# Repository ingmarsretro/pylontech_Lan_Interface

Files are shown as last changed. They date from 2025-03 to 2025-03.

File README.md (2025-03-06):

# Universal LAN Board with WT32-ETH01 Module for Pylontech and more

This project introduces a universal board that can be used for various purposes. The heart of the board is a WT32-ETH01 module with an ESP32 and a LAN interface. Depending on the configuration and software, the board can fulfill different functions.

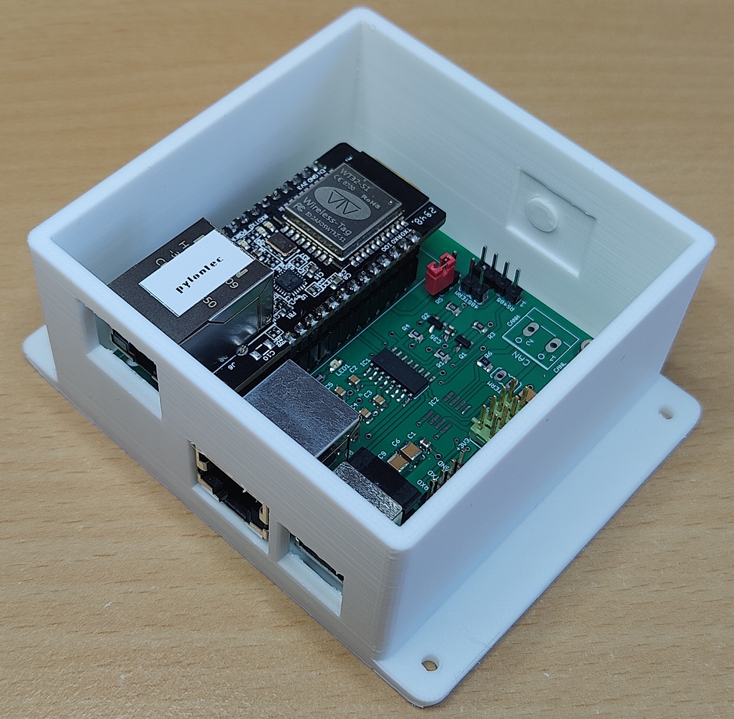
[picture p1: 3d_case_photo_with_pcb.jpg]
3D Case Photo with PCB


## Features

### Communication with Pylontech Solar Batteries

The board can communicate with Pylontech solar batteries (US2000, US3000c, ...) via the serial console interface. For this purpose, the software from the following repositories has been adapted from ESP8266 to ESP32:
- [Pylontech-Battery-Monitoring by irekzielinski](https://github.com/irekzielinski/Pylontech-Battery-Monitoring)
- [PylontechMonitoring by hidaba](https://github.com/hidaba/PylontechMonitoring)

Thus, the Pylontech batteries can communicate via LAN over MQTT with, for example, Homeassistant.

### Communication with Microinverters (e.g., Hoymiles)

The board can communicate with microinverters such as Hoymiles via OpenDTU software and the NRF24L01+ module:
- [OpenDTU by tbnobody](https://github.com/tbnobody/OpenDTU)

A configuration file for OpenDTU with WS32ETH 01 is included and can be adjusted if necessary. Further information for current software can be found on the OpenDTU GitHub.

### Communication via CAN or RS485

The board can communicate with various devices via CAN or RS485. Projects for this will be developed or published as needed.

## Installation

1. **Prepare Hardware:**
   - Assemble the board according to the desired functionality (e.g., NRF24L01+ module for OpenDTU or MAX3232 along with console connector for Pylontech).
   - Connect the WT32-ETH01 module to your network and the assembled function to your device (e.g., serial console interface for Pylontech batteries).

2. **Install Software:**
   - Download the appropriate software from the repositories mentioned above.
   - Adjust the configuration files to your needs.
   - Flash the software onto the WT32-ETH01 module. (In the Pylontech software script, IP addresses need to be adjusted. Use Arduino IDE for compiling.)
     To flash the software, a USB_RS232 interface is required. The "Prog" jumper must be set. The programmer is connected to the "TO-FTDI" pins.

3. **Configuration:**
   - When using with Pylontech, enter the address specified in the code in your web browser. If the connection is OK, the data of the Pylontech batteries will be displayed in the browser.
     If an MQTT server is present and correctly specified in the code, MQTT messages will be sent.
   - When using with OpenDTU, configure the network via the OpenDTU access point after flashing the firmware and load the wt32mapping.json file.
   - Ensure all connections are correct and start the system.

## Usage

Depending on configuration and software, you can use the board for various purposes:
- **Pylontech Batteries:** Monitor and control your Pylontech solar batteries via MQTT and integrate them into Homeassistant.
- **Microinverter:** Communicate with microinverters like Hoymiles via OpenDTU and monitor your solar system.
- **CAN/RS485:** Develop your own projects for communication via CAN or RS485 with various devices.

## License
free

# Universalboard mit WT32-ETH01 Modul

Dieses Projekt stellt ein Universalboard vor, das für verschiedene Zwecke verwendet werden kann. Das Herzstück des Boards ist ein WT32-ETH01 Modul mit einem ESP32 und einem LAN Interface. Je nach Bestückung und Software kann das Board verschiedene Funktionen erfüllen.

3D Case Photo with PCB

## Funktionen

### Kommunikation mit Pylontech Solarbatterien

Das Board kann mit den Solarbatterien von Pylontech (US2000, US3000c, ...) über die serielle Console-Schnittstelle kommunizieren. Dafür wurde die Software von folgenden Repositories vom ESP8266 auf den ESP32 angepasst:
- [Pylontech-Battery-Monitoring von irekzielinski](https://github.com/irekzielinski/Pylontech-Battery-Monitoring)
- [PylontechMonitoring von hidaba](https://github.com/hidaba/PylontechMonitoring)

So können die Pylontech Batterien per LAN über MQTT mit z.B. Homeassistant kommunizieren.

### Kommunikation mit Microinvertern (z.B. Hoymiles)

Das Board kann mit Microinvertern wie z.B. Hoymiles per OpenDTU Software und dem NRF24L01+ Modul kommunizieren:
- [OpenDTU von tbnobody](https://github.com/tbnobody/OpenDTU)

Ein Konfigurationsfile für openDTU mit WS32ETH 01 ist beigelegt und kann ggf angepasst werden. Weitere für aktuelle Software auf openDTU git

### Kommunikation über CAN oder RS485

Das Board kann über CAN bzw. RS485 mit beliebigen Geräten kommunizieren. Projekte dazu werden entwickelt bzw. veröffentlicht, sobald sie benötigt werden.

## Installation

1. **Hardware vorbereiten:**
   - Bestücke das Board je nach gewünschter Funktionalität (z.B. NRF24L01+ Modul für OpenDTU oder MAX3232 samt Console Conector für Pylontech)
   - Verbinde das WT32-ETH01 Modul mit deinem Netzwerk und die bestückte Funtkion mit deinem Gerät (z.B. serielle Console-Schnittstelle für Pylontech Batterien).

2. **Software installieren:**
   - Lade die entsprechende Software aus den oben genannten Repositories herunter. 
   - Passe die Konfigurationsdateien an deine Bedürfnisse an. 
   - Flashe die Software auf das WT32-ETH01 Modul. (im Pylontech Softwarescript müssen die IP Adressen angepasst werden. zum kompilieren z.b. Adruino IDE verwenden)
     Zum flashen der Software ist ein USB_RS232 Interface notwendig. Der Jumper "Prog" muss gesetzt sein. Der Programmer wird an den Pins "TO-FTDI" angeschlossen

3. **Konfiguration:**
   - bei Verwendung mit Pylontech im Webbrowser die im code eingegeben Adresse eingeben. Ist die Verbindung OK werden die Daten der Pylontech Batterien im Browser angezeigt.
     Ist der MQTT Server vorhanden und im code richtig angegeben dann werden die mqtt messages gesendet
   - bei Verwednung mit openDTU ist nach dem Flashen der Firmware über den openDTU accesspoint das Netzwerk zu konfigurieren und das wt32mapping.json file zu laden.
   - Stelle sicher, dass alle Verbindungen korrekt sind und starte das System.

## Nutzung

Je nach Bestückung und Software kannst du das Board für verschiedene Zwecke nutzen:
- **Pylontech Batterien:** Überwache und steuere deine Pylontech Solarbatterien über MQTT und integriere sie in Homeassistant.
- **Microinverter:** Kommuniziere mit Microinvertern wie Hoymiles über OpenDTU und überwache deine Solaranlage.
- **CAN/RS485:** Entwickle eigene Projekte zur Kommunikation über CAN oder RS485 mit verschiedenen Geräten.

## Lizenz
free

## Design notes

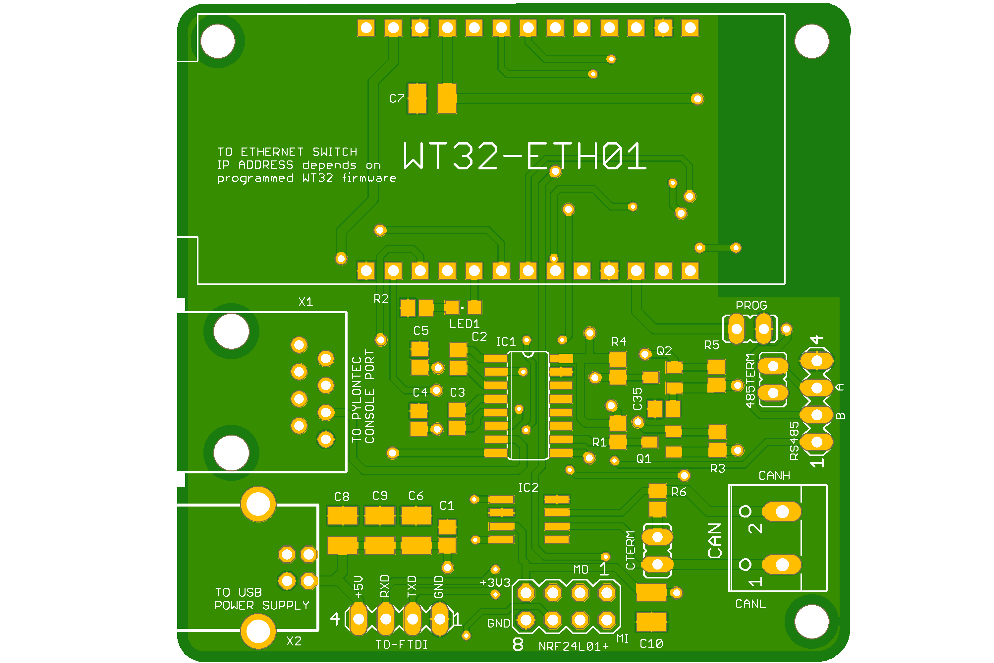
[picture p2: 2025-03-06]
PCB_design/pylontec_LAN_interface.png

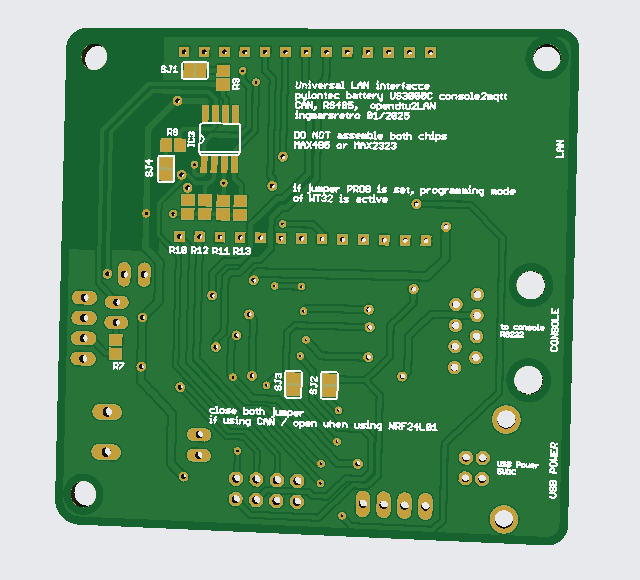
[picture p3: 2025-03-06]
PCB_design/pcb_bott.PNG

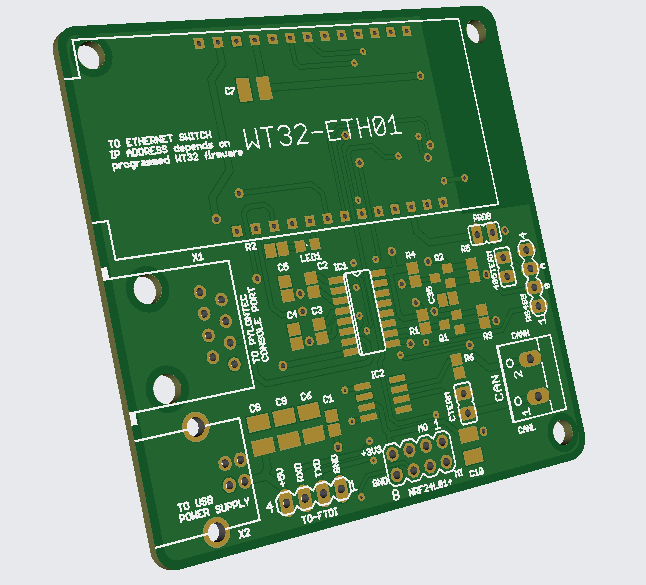
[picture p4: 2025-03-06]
PCB_design/pcb_top.PNG

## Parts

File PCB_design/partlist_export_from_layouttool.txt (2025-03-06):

Partlist

Exported from pylontec_LAN_interface.sch at 06.03.2025 11:38

Assembly variant: 

Part      Value          Device              Package          Library                 Sheet

485TERM                  JP1E                JP1              jumper                  1
C1        100nF          C-EUC0805           C0805            resistor                1
C2        47n            C-EUC0805           C0805            resistor                1
C3        330n           C-EUC0805           C0805            resistor                1
C4        330n           C-EUC0805           C0805            resistor                1
C5        330n           C-EUC0805           C0805            resistor                1
C6        1uF            C-EUC1210           C1210            rcl                     1
C7        1uF            C-EUC1210           C1210            rcl                     1
C8                       C-EUC1210           C1210            rcl                     1
C9                       C-EUC1210           C1210            rcl                     1
C10       1uF            C-EUC1210           C1210            rcl                     1
C35       100nF          C-EUC0805           C0805            resistor                1
CAN                      W237-102            W237-102         con-wago-500            1
CTERM                    JP1E                JP1              jumper                  1
IC1       MAX3232CSE     MAX3232CSE          SO16             maxim                   1
IC2       SN65HVD230     TJA1040             SO8              nxp                     1
IC3       MAX485         MAX481CSA           SO08             maxim                   1
LED1                     LED_LEDCHIPLED_0805 LED_CHIPLED_0805 arduino_Uno_ref         1
NRF24L01+                MA04-2              MA04-2           con-lstb                1
PROG                     JP1E                JP1              jumper                  1
Q1        BSS123         BSS123              SOT23            transistor-small-signal 1
Q2        BSS123         BSS123              SOT23            transistor-small-signal 1
R1        10k            R-EU_R0805          R0805            resistor                1
R2        180R           R-EU_R0805          R0805            resistor                1
R3        10k            R-EU_R0805          R0805            resistor                1
R4        10k            R-EU_R0805          R0805            resistor                1
R5        10k            R-EU_R0805          R0805            resistor                1
R6        120R           R-EU_R0805          R0805            resistor                1
R7        120R           R-EU_R0805          R0805            resistor                1
R8        1k             R-EU_R0805          R0805            resistor                1
R9        1k             R-EU_R0805          R0805            resistor                1
R10       10k            R-EU_R0805          R0805            resistor                1
R11       10k            R-EU_R0805          R0805            resistor                1
R12       10k            R-EU_R0805          R0805            resistor                1
R13       10k            R-EU_R0805          R0805            resistor                1
RS485                    MA04-1              MA04-1           con-lstb                1
SJ1                      SJ                  SJ               jumper                  1
SJ2                      SJ                  SJ               jumper                  1
SJ3                      SJ                  SJ               jumper                  1
SJ4                      SJ                  SJ               jumper                  1
TO-FTDI                  MA04-1              MA04-1           con-lstb                1
U$2       WT32-ETH01     WT32-ETH01          WT32-ETH01       WT32-ETH01              1
X1        RJ45-8L-B      RJ45-8L-B           RJ45-NO-SHIELD   con-tycoelectronics     1
X2                       SMARTPRJ_PN61729    SMARTPRJ_PN61729 arduino_Uno_ref         1

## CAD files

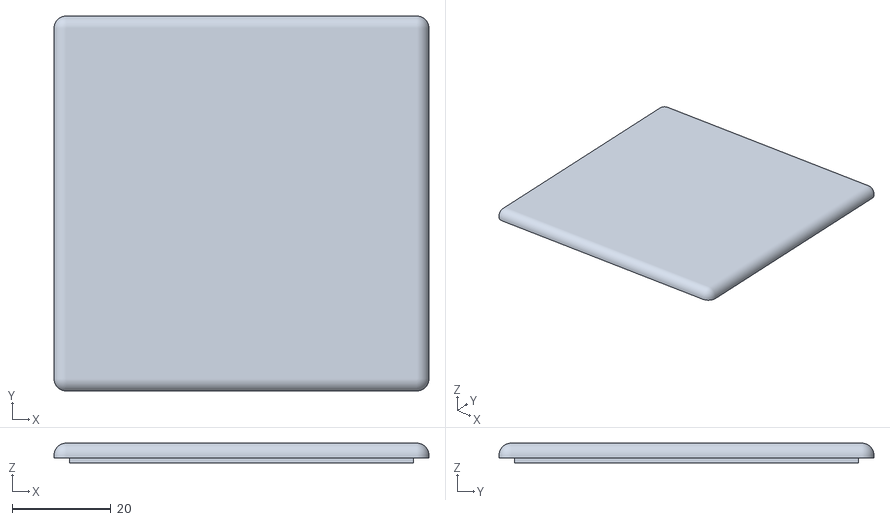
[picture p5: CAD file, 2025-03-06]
case_for_pcb/deckel_fusioned.stl
76.0 x 76.0 x 4.00

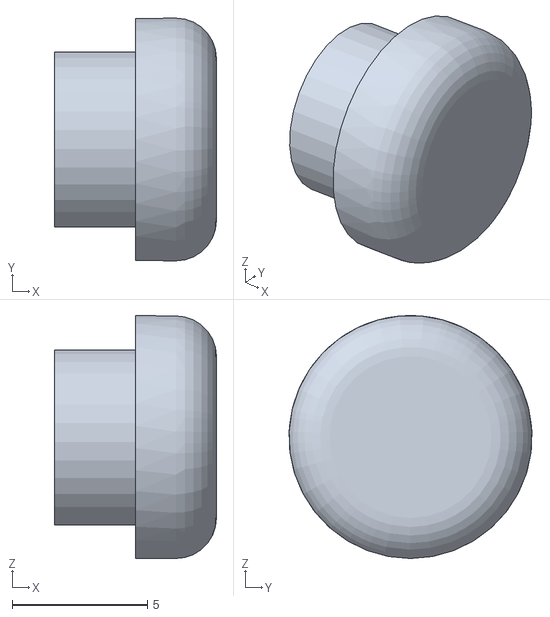
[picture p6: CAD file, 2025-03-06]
case_for_pcb/Stoppel_antenne.stl
6.00 x 8.99 x 9.00

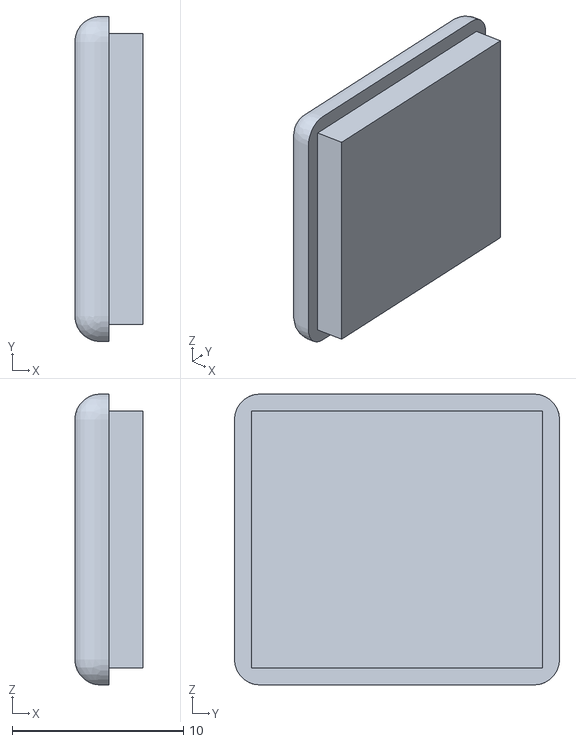
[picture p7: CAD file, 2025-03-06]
case_for_pcb/Stoppel_console.stl
4.00 x 19.0 x 17.0

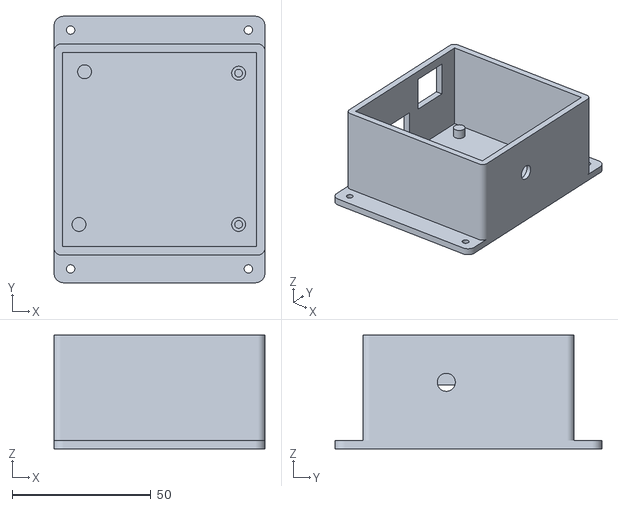
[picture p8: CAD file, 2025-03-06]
case_for_pcb/gehäuse_fusioned.stl
76.0 x 96.0 x 41.0

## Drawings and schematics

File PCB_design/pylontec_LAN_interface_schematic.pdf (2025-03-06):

7 IC3 | GND VCC8 5 IC3P | R⁷
A

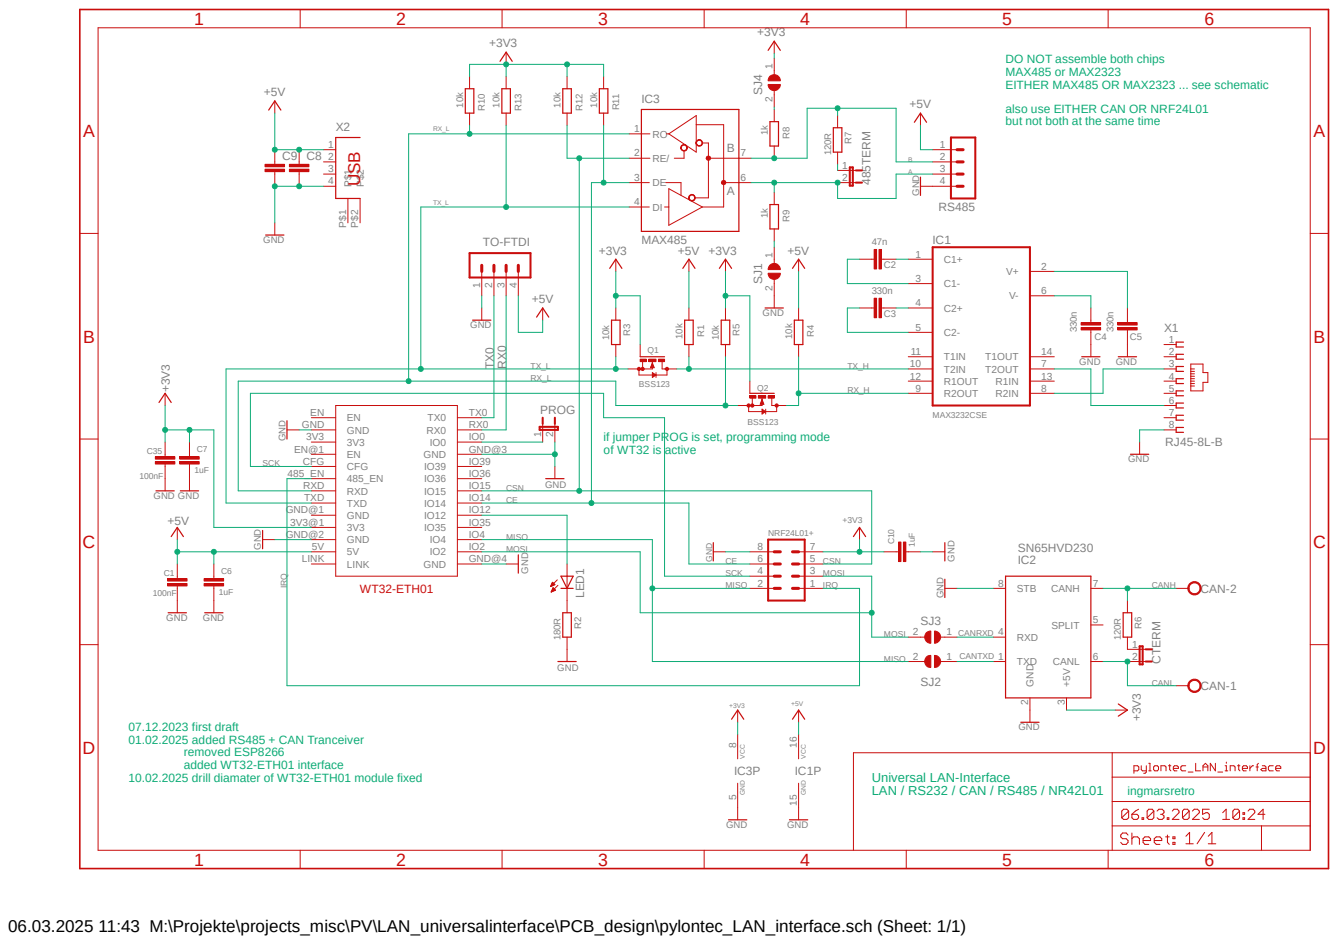
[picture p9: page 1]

DO NOT assemble both chips
MAX485 or MAX2323
EITHER MAX485 OR MAX2323 ... see schematic
also use EITHER CAN OR NRF24L01
but not both at the same time

if jumper PROG is set, programming mode
of WT32 is active
GND180R GND

10.02.2025 drill diamater of WT32-ETH01 module fixed

06.03.2025 11:43 M:\Projekte\projects_misc\PV\LAN_universalinterface\PCB_design\pylontec_LAN_interface.sch (Sheet: 1/1)

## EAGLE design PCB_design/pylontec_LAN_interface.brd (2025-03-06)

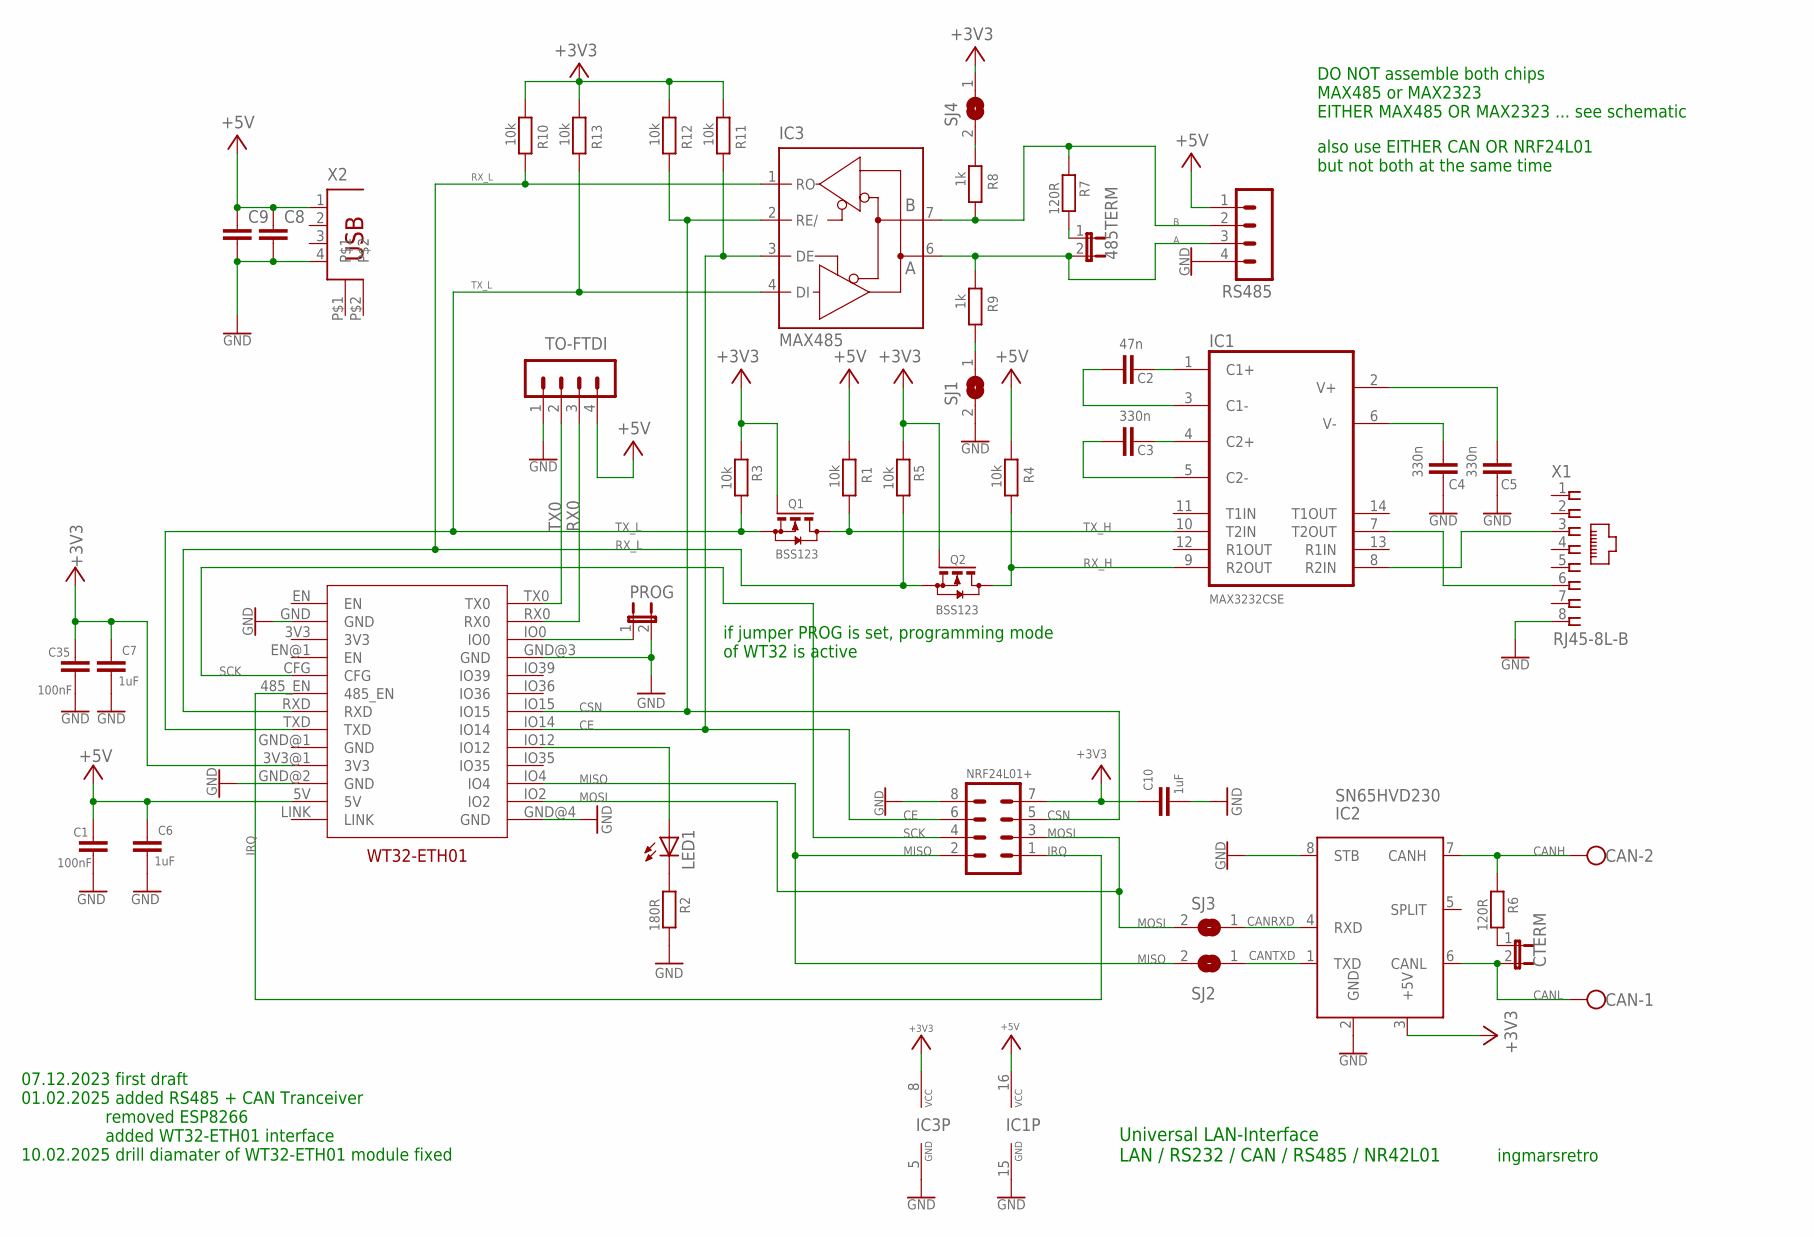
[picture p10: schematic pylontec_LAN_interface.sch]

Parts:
485TERM: JP1E; JP1
C1, C35: 100nF; C0805
C2: 47n; C0805
C3, C4, C5: 330n; C0805
C6, C7, C10: 1uF; C1210
C8, C9: C-EUC1210; C1210
CAN: W237-102
CTERM: JP1E; JP1
IC1: MAX3232CSE; SO16
IC2: SN65HVD230; SO8
IC3: MAX485; SO08
LED1: LED_LEDCHIPLED_0805; LED_CHIPLED_0805
NRF24L01+: MA04-2
PROG: JP1E; JP1
Q1, Q2: BSS123; SOT23
R1, R3, R4, R5, R10, R11, R12, R13: 10k; R0805
R2: 180R; R0805
R6, R7: 120R; R0805
R8, R9: 1k; R0805
RS485: MA04-1
SJ1, SJ2, SJ3, SJ4: SJ
TO-FTDI: MA04-1
U$2: WT32-ETH01
X1: RJ45-8L-B; RJ45-NO-SHIELD
X2: SMARTPRJ_PN61729

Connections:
+3V3: C7.1, C10.1, C35.2, IC2.3 (+5V), IC3.8 (VCC), NRF24L01+.7, Q1.1 (G), Q2.1 (G), R3.1, R5.1, R10.1, R11.1, R12.1, R13.1, SJ4.1, U$2.3V3@1 (3V3)
+5V: C1.2, C6.1, C8.1, C9.1, IC1.16 (VCC), R1.1, R4.1, RS485.1, TO-FTDI.4, U$2.5V, X2.1
A: 485TERM.2, IC3.6 (A), R9.1, RS485.3
B: IC3.7 (B), R7.1, R8.2, RS485.2
CANH: CAN.2, IC2.7 (CANH), R6.1
CANL: CAN.1, CTERM.2, IC2.6 (CANL)
CANRXD: IC2.4 (RXD), SJ3.1
CANTXD: IC2.1 (TXD), SJ2.1
CE: IC3.3 (DE), NRF24L01+.6, R11.2, U$2.IO14
CSN: IC3.2 (RE/), NRF24L01+.5, R12.2, U$2.IO15
GND: C1.1, C4.2, C5.2, C6.2, C7.2, C8.2, C9.2, C10.2, C35.1, IC1.15 (GND), IC2.2 (GND), IC2.8 (STB), IC3.5 (GND), NRF24L01+.8, PROG.2, R2.2, RS485.4, SJ1.2, TO-FTDI.1, U$2.GND, U$2.GND@2 (GND), U$2.GND@3 (GND), U$2.GND@4 (GND), X1.8, X2.4
IRQ: NRF24L01+.1, U$2.485_EN
MISO: NRF24L01+.2, SJ2.2, U$2.IO4
MOSI: NRF24L01+.3, SJ3.2, U$2.IO2
unnamed: IC1.8 (R2IN), X1.3
unnamed: C2.1, IC1.1 (C1+)
unnamed: PROG.1, U$2.IO0
unnamed: C2.2, IC1.3 (C1-)
unnamed: C3.1, IC1.4 (C2+)
unnamed: C3.2, IC1.5 (C2-)
unnamed: C4.1, IC1.6 (V-)
unnamed: C5.1, IC1.2 (V+)
unnamed: IC1.7 (T2OUT), X1.6
unnamed: LED1.A, U$2.IO12
unnamed: LED1.C, R2.1
unnamed: 485TERM.1, R7.2
unnamed: CTERM.1, R6.2
unnamed: R9.2, SJ1.1
unnamed: R8.1, SJ4.2
RX0: TO-FTDI.3, U$2.RX0
RX_H: IC1.9 (R2OUT), Q2.3 (D), R4.2
RX_L: IC3.1 (RO), Q2.2 (S), R5.2, R10.2, U$2.RXD
SCK: NRF24L01+.4, U$2.CFG
TX0: TO-FTDI.2, U$2.TX0
TX_H: IC1.10 (T2IN), Q1.3 (D), R1.2
TX_L: IC3.4 (DI), Q1.2 (S), R3.2, R13.2, U$2.TXD

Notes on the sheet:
ingmarsretro
Universal LAN-Interface LAN / RS232 / CAN / RS485 / NR42L01
07.12.2023 first draft 01.02.2025 added RS485 + CAN Tranceiver removed ESP8266 added WT32-ETH01 interface 10.02.2025 drill diamater of WT32-ETH01 module fixed
if jumper PROG is set, programming mode of WT32 is active
DO NOT assemble both chips MAX485 or MAX2323 EITHER MAX485 OR MAX2323 ... see schematic
also use EITHER CAN OR NRF24L01 but not both at the same time

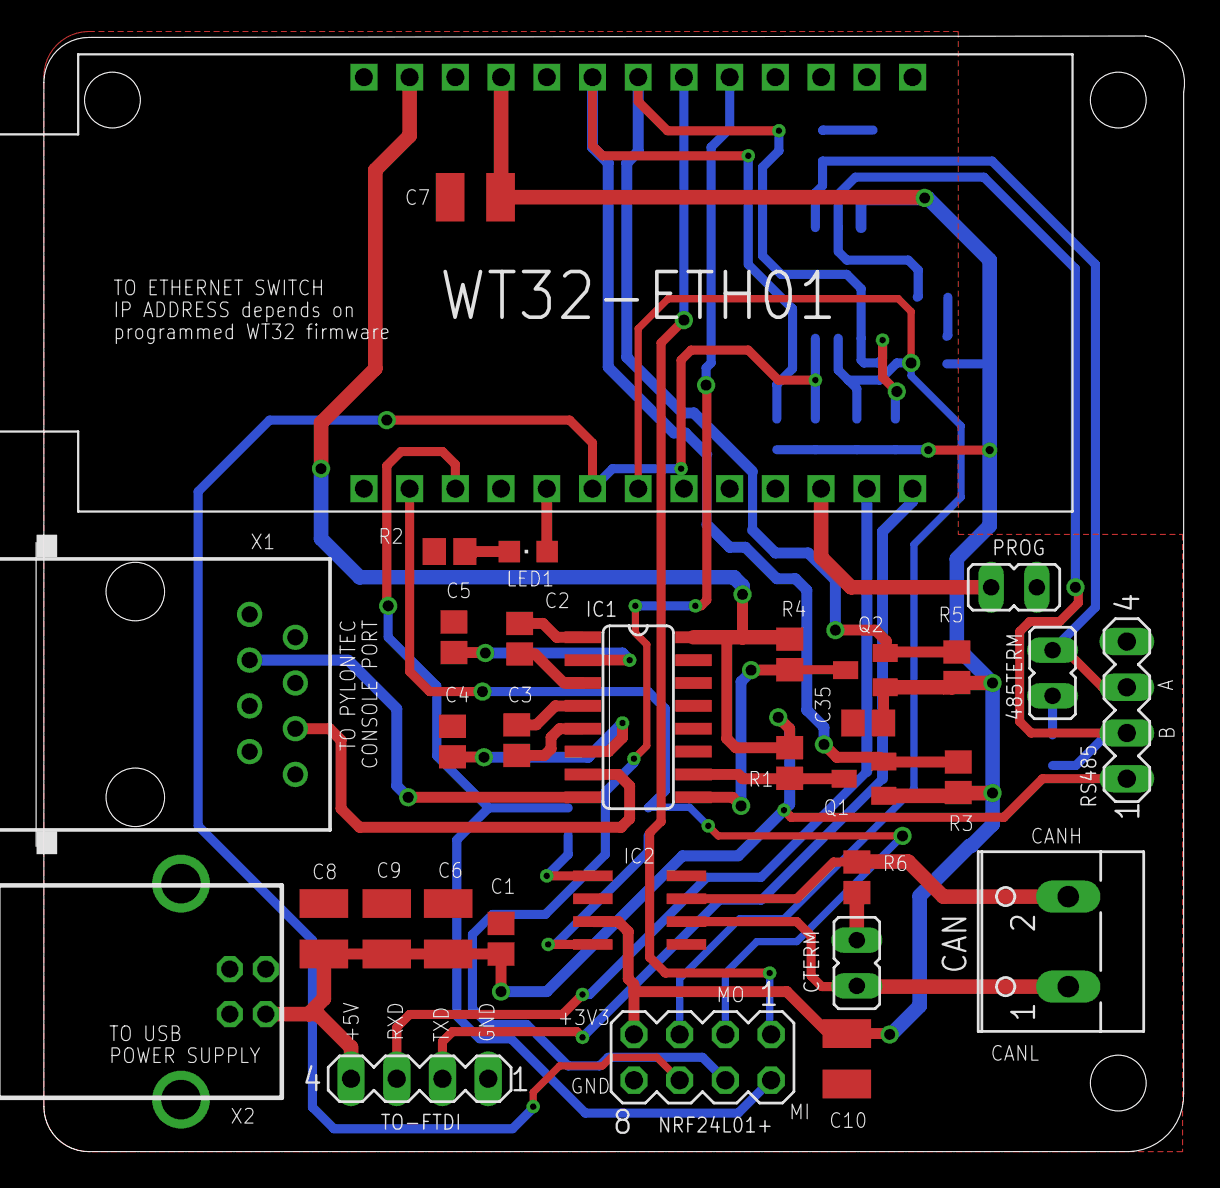
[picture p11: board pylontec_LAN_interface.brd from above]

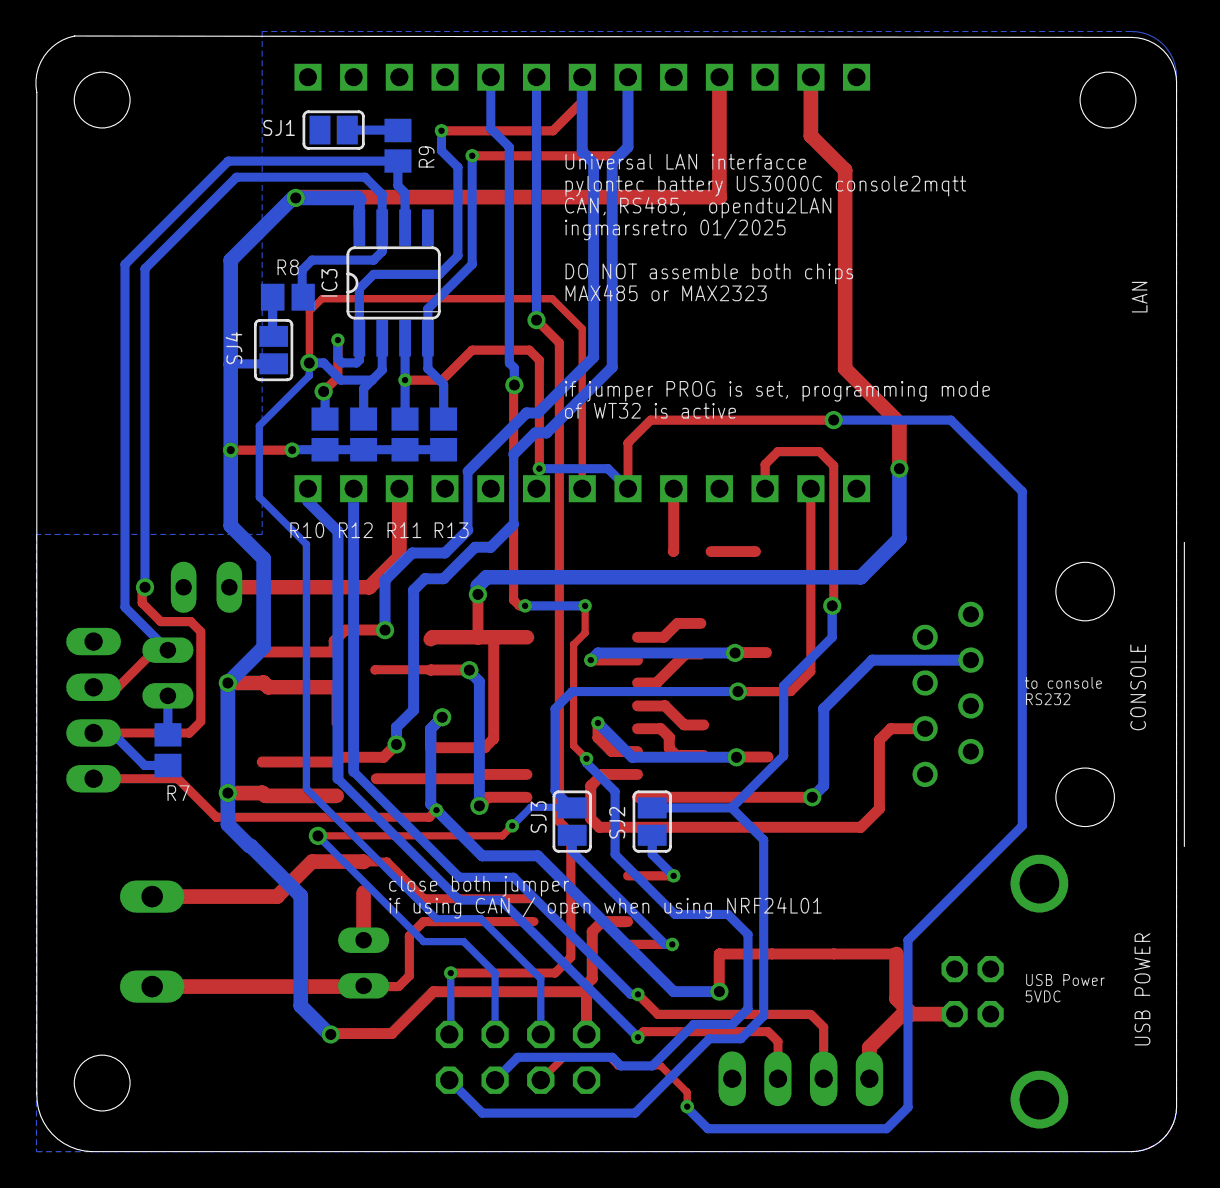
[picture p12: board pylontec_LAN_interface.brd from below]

Board: 2 copper layers, 63.4 x 62.0 mm, 44 parts (12 on the bottom side), 36 nets.

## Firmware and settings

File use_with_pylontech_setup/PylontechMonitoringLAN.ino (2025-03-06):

//Pylontec2MQTT interface
//code by https://github.com/irekzielinski/Pylontech-Battery-Monitoring
//    and https://github.com/hidaba/PylontechMonitoring
// the original code used WEMOS Boards with ESP8266
// code changed to use with WT32-ETH01 Board for use with LAN connection
// changes by ingmarsretro 01/2025
#include <ETH.h>
#include <WiFi.h>
#include <ESPmDNS.h>
#include <ArduinoOTA.h>
#include <WebServer.h>
#include <circular_log.h>
#include <ArduinoJson.h>
#include <NTPClient.h>
#include "TimerConfig.h"
#include <ESP32TimerInterrupt.h>

//+++ START CONFIGURATION +++
#define LED 12
#define RXD2 5
#define TXD2 17
#define HOSTNAME "mppsolar-pylontec"

#define STATIC_IP
IPAddress local_IP(192, 168, xx, yy);
IPAddress subnet(255, 255, 255, 0);
IPAddress gateway(192, 168, yy, zz);
IPAddress primaryDNS(192, 168, yy, ww);

//Uncomment for authentication page
//#define AUTHENTICATION
const char* www_username = "admin";
const char* www_password = "password";

//IMPORTANT: Uncomment this line if you want to enable MQTT (and fill correct MQTT_ values below):
#define ENABLE_MQTT

// Set offset time in seconds to adjust for your timezone, for example:
// GMT +1 = 3600
// GMT 0 = 0
#define GMT 3600

//NOTE 1: if you want to change what is pushed via MQTT - edit function: pushBatteryDataToMqtt.
//NOTE 2: MQTT_TOPIC_ROOT is where battery will push MQTT topics. For example "soc" will be pushed to: "home/grid_battery/soc"
#define MQTT_SERVER        "192.168.aa.bb"
#define MQTT_PORT          1883
#define MQTT_USER          ""
#define MQTT_PASSWORD      ""
#define MQTT_TOPIC_ROOT    "ingmarsretro/pylontec/"  //this is where mqtt data will be pushed
#define MQTT_PUSH_FREQ_SEC 2  //maximum mqtt update frequency in seconds
//+++   END CONFIGURATION +++

#ifdef ENABLE_MQTT
#include <PubSubClient.h>
WiFiClient ethClient;
PubSubClient mqttClient(ethClient);
#endif //ENABLE_MQTT

//text response
char g_szRecvBuff[7000];

const long utcOffsetInSeconds = GMT;
char daysOfTheWeek[7][12] = {"Sunday", "Monday", "Tuesday", "Wednesday", "Thursday", "Friday", "Saturday"};
// Define NTP Client to get time
WiFiUDP ntpUDP;
NTPClient timeClient(ntpUDP, "pool.ntp.org", utcOffsetInSeconds);


//ESP8266WebServer server(80);
WebServer server(80);
circular_log<7000> g_log;
bool ntpTimeReceived = false;
int g_baudRate = 0;

void Log(const char* msg)
{
  g_log.Log(msg);
}

//Define Interrupt Timer to Calculate Power meter every second (kWh)
#define USING_TIM_DIV1 true                                             // for shortest and most accurate timer
//ESP8266Timer ITimer;
ESP32Timer ITimer(0); // Use timer 0
bool setInterval(unsigned long interval, timer_callback callback);      // interval (in microseconds)
#define TIMER_INTERVAL_MS 1000

//Global Variables for the Power Meter - accessible from the calculating interrupt und from main
unsigned long powerIN = 0;       //WS gone in to the BAttery
unsigned long powerOUT = 0;      //WS gone out of the Battery
//Global Variables for the Power Meter - Überlauf
unsigned long powerINWh = 0;       //WS gone in to the BAttery
unsigned long powerOUTWh = 0;      //WS gone out of the Battery

void setup() {
  
  memset(g_szRecvBuff, 0, sizeof(g_szRecvBuff)); //clean variable
  
  pinMode(LED, OUTPUT); 
  //digitalWrite(LED, HIGH);//high is off
  digitalWrite(LED, LOW);//low is off

  // put your setup code here, to run once:
  //WiFi.mode(WIFI_STA);
  //WiFi.persistent(false); //our credentialss are hardcoded, so we don't need ESP saving those each boot (will save on flash wear)
  //WiFi.hostname(HOSTNAME);

  ETH.begin();
  ETH.setHostname(HOSTNAME);
    #ifdef STATIC_IP
     ETH.config(local_IP, gateway, subnet, primaryDNS);
  #endif
 
  for(int ix=0; ix<10; ix++)
  {
    Log("Wait for LAN Connection");
    if (ETH.linkUp()) {
        Serial2.println("Ethernet connected");
        Serial2.print("IP Address: ");
        Serial2.println(ETH.localIP());
    } else {
        Serial2.println("Failed to connect to Ethernet");
    }

    delay(1000);
  }

  ArduinoOTA.setHostname(HOSTNAME);
  ArduinoOTA.begin();
  server.on("/", handleRoot);
  server.on("/log", handleLog);
  server.on("/req", handleReq);
  server.on("/jsonOut", handleJsonOut);
  server.on("/reboot", [](){
    #ifdef AUTHENTICATION
    if (!server.authenticate(www_username, www_password)) {
      return server.requestAuthentication();
    }
    #endif
    ESP.restart();
  });
  
  server.begin(); 
  
  timeClient.begin();

  
#ifdef ENABLE_MQTT
  mqttClient.setServer(MQTT_SERVER, MQTT_PORT);
#endif

  Log("Boot event");
  
}

void handleLog()
{
  #ifdef AUTHENTICATION
  if (!server.authenticate(www_username, www_password)) {
    return server.requestAuthentication();
  } 
  #endif
  server.send(200, "text/html", g_log.c_str());
}

void switchBaud(int newRate)
{
  if(g_baudRate == newRate)
  {
    return;
  }
  
  if(g_baudRate != 0)
  {
    Serial2.flush();
    delay(20);
    Serial2.end();
    delay(20);
  }

  char szMsg[50];
  snprintf(szMsg, sizeof(szMsg)-1, "New baud: %d", newRate);
  Log(szMsg);
  
  Serial2.begin(newRate,SERIAL_8N1, RXD2, TXD2);
  g_baudRate = newRate;

  delay(20);
}

void waitForSerial()
{
  for(int ix=0; ix<150;ix++)
  {
    if(Serial2.available()) break;
    delay(10);
  }
}

int readFromSerial()
{
  memset(g_szRecvBuff, 0, sizeof(g_szRecvBuff));
  int recvBuffLen = 0;
  bool foundTerminator = true;
  
  waitForSerial();
  
  while(Serial2.available())
  {
    char szResponse[256] = "";
    const int readNow = Serial2.readBytesUntil('>', szResponse, sizeof(szResponse)-1); //all commands terminate with "$$\r\n\rpylon>" (no new line at the end)
    if(readNow > 0 && 
       szResponse[0] != '\0')
    {
      if(readNow + recvBuffLen + 1 >= (int)(sizeof(g_szRecvBuff)))
      {
        Log("WARNING: Read too much data on the console!");
        break;
      }
      
      strcat(g_szRecvBuff, szResponse);
      recvBuffLen += readNow;

      if(strstr(g_szRecvBuff, "$$\r\n\rpylon"))
      {
        strcat(g_szRecvBuff, ">"); //readBytesUntil will skip this, so re-add
        foundTerminator = true;
        break; //found end of the string
      }

      if(strstr(g_szRecvBuff, "Press [Enter] to be continued,other key to exit"))
      {
        //we need to send new line character so battery continues the output
        Serial2.write("\r");
      }

      waitForSerial();
    }
  }

  if(recvBuffLen > 0 )
  {
    if(foundTerminator == false)
    {
      Log("Failed to find pylon> terminator");
    }
  }

  return recvBuffLen;
}

bool readFromSerialAndSendResponse()
{
  const int recvBuffLen = readFromSerial();
  if(recvBuffLen > 0)
  {
    server.sendContent(g_szRecvBuff);
    return true;
  }

  return false;
}

bool sendCommandAndReadSerialResponse(const char* pszCommand)
{
  switchBaud(115200);

  if(pszCommand[0] != '\0')
  {
    Serial2.write(pszCommand);
  }
  Serial2.write("\n");

  const int recvBuffLen = readFromSerial();
  if(recvBuffLen > 0)
  {
    return true;
  }

  //wake up console and try again:
  wakeUpConsole();

  if(pszCommand[0] != '\0')
  {
    Serial2.write(pszCommand);
  }
  Serial2.write("\n");

  return readFromSerial() > 0;
}

void handleReq()
{
  #ifdef AUTHENTICATION
  if (!server.authenticate(www_username, www_password)) {
    return server.requestAuthentication();
  }
  #endif
  bool respOK;
  if(server.hasArg("code") == false)
  {
    respOK = sendCommandAndReadSerialResponse("");
  }
  else
  {
    respOK = sendCommandAndReadSerialResponse(server.arg("code").c_str());
  }

  handleRoot();
}



void handleJsonOut()
{
  #ifdef AUTHENTICATION
  if (!server.authenticate(www_username, www_password)) {
    return server.requestAuthentication();
  }
  #endif
  if(sendCommandAndReadSerialResponse("pwr") == false)
  {
    server.send(500, "text/plain", "Failed to get response to 'pwr' command");
    return;
  }

  parsePwrResponse(g_szRecvBuff);
  prepareJsonOutput(g_szRecvBuff, sizeof(g_szRecvBuff));
  server.send(200, "application/json", g_szRecvBuff);
}

void handleRoot() {
  #ifdef AUTHENTICATION
  if (!server.authenticate(www_username, www_password)) {
    return server.requestAuthentication();
  }
  #endif
  timeClient.update(); //get ntp datetime
  unsigned long days = 0, hours = 0, minutes = 0;
  unsigned long val = os_getCurrentTimeSec();
  days = val / (3600*24);
  val -= days * (3600*24);
  hours = val / 3600;
  val -= hours * 3600;
  minutes = val / 60;
  val -= minutes*60;

  time_t epochTime = timeClient.getEpochTime();
  String formattedTime = timeClient.getFormattedTime();
  //Get a time structure
  struct tm *ptm = gmtime ((time_t *)&epochTime); 
  int currentMonth = ptm->tm_mon+1;

  static char szTmp[9500] = "";  
  long timezone= GMT / 3600;
  snprintf(szTmp, sizeof(szTmp)-1, "<html><b>Pylontech Battery LAN Interface</b><br>Time GMT: %s (%s %d)<br>Uptime: %02d:%02d:%02d.%02d<br><br>free heap: %u<br>MQTT-Server: %s<br>MQTT-root topic: %s", 
            formattedTime, "GMT ", timezone,
            (int)days, (int)hours, (int)minutes, (int)val, 
            ESP.getFreeHeap(),MQTT_SERVER,MQTT_TOPIC_ROOT);
  
  strncat(szTmp, "<BR><a href='/log'>Runtime log</a><HR>", sizeof(szTmp)-1);
  strncat(szTmp, "<form action='/req' method='get'>Command:<input type='text' name='code'/><input type='submit'> <a href='/req?code=pwr'>PWR</a> | <a href='/req?code=pwr%201'>Power 1</a> |  <a href='/req?code=pwr%202'>Power 2</a> | <a href='/req?code=pwr%203'>Power 3</a> | <a href='/req?code=pwr%204'>Power 4</a> | <a href='/req?code=help'>Help</a> | <a href='/req?code=log'>Event Log</a> | <a href='/req?code=time'>Time</a><br>", sizeof(szTmp)-1);
  //strncat(szTmp, "<form action='/req' method='get'>Command:<input type='text' name='code'/><input type='submit'><a href='/req?code=pwr'>Power</a> | <a href='/req?code=help'>Help</a> | <a href='/req?code=log'>Event Log</a> | <a href='/req?code=time'>Time</a><br>", sizeof(szTmp)-1);
  strncat(szTmp, "<textarea rows='80' cols='180'>", sizeof(szTmp)-1);
  //strncat(szTmp, "<textarea rows='45' cols='180'>", sizeof(szTmp)-1);
  strncat(szTmp, g_szRecvBuff, sizeof(szTmp)-1);
  strncat(szTmp, "</textarea></form>", sizeof(szTmp)-1);
  strncat(szTmp, "</html>", sizeof(szTmp)-1);
  //send page
  server.send(200, "text/html", szTmp);
}

unsigned long os_getCurrentTimeSec()
{
  static unsigned int wrapCnt = 0;
  static unsigned long lastVal = 0;
  unsigned long currentVal = millis();

  if(currentVal < lastVal)
  {
    wrapCnt++;
  }

  lastVal = currentVal;
  unsigned long seconds = currentVal/1000;
  
  //millis will wrap each 50 days, as we are interested only in seconds, let's keep the wrap counter
  return (wrapCnt*4294967) + seconds;
}

void wakeUpConsole()
{
  switchBaud(1200);

  //byte wakeUpBuff[] = {0x7E, 0x32, 0x30, 0x30, 0x31, 0x34, 0x36, 0x38, 0x32, 0x43, 0x30, 0x30, 0x34, 0x38, 0x35, 0x32, 0x30, 0x46, 0x43, 0x43, 0x33, 0x0D};
  //Serial.write(wakeUpBuff, sizeof(wakeUpBuff));
  Serial.write("~20014682C0048520FCC3\r");
  delay(1000);

  byte newLineBuff[] = {0x0E, 0x0A};
  switchBaud(115200);
  
  for(int ix=0; ix<10; ix++)
  {
    Serial.write(newLineBuff, sizeof(newLineBuff));
    delay(1000);

    if(Serial.available())
    {
      while(Serial.available())
      {
        Serial.read();
      }
      
      break;
    }
  }
}

#define MAX_PYLON_BATTERIES 8

struct pylonBattery
{
  bool isPresent;
  long  soc;     //Coulomb in %
  long  voltage; //in mW
  long  current; //in mA, negative value is discharge
  long  tempr;   //temp of case or BMS?
  long  cellTempLow;
  long  cellTempHigh;
  long  cellVoltLow;
  long  cellVoltHigh;
  char baseState[9];    //Charge | Dischg | Idle
  char voltageState[9]; //Normal
  char currentState[9]; //Normal
  char tempState[9];    //Normal
  char time[20];        //2019-06-08 04:00:29
  char b_v_st[9];       //Normal  (battery voltage?)
  char b_t_st[9];       //Normal  (battery temperature?)

  bool isCharging()    const { return strcmp(baseState, "Charge")   == 0; }
  bool isDischarging() const { return strcmp(baseState, "Dischg")   == 0; }
  bool isIdle()        const { return strcmp(baseState, "Idle")     == 0; }
  bool isBalancing()   const { return strcmp(baseState, "Balance")  == 0; }
  

  bool isNormal() const
  {
    if(isCharging()    == false &&
       isDischarging() == false &&
       isIdle()        == false &&
       isBalancing()   == false)
    {
      return false; //base state looks wrong!
    }

    return  strcmp(voltageState, "Normal") == 0 &&
            strcmp(currentState, "Normal") == 0 &&
            strcmp(tempState,    "Normal") == 0 &&
            strcmp(b_v_st,       "Normal") == 0 &&
            strcmp(b_t_st,       "Normal") == 0 ;
  }
};

struct batteryStack
{
  int batteryCount;
  int soc;  //in %, if charging: average SOC, otherwise: lowest SOC
  int temp; //in mC, if highest temp is > 15C, this will show the highest temp, otherwise the lowest
  long currentDC;    //mAh current going in or out of the battery
  long avgVoltage;    //in mV
  char baseState[9];  //Charge | Dischg | Idle | Balance | Alarm!

  
  pylonBattery batts[MAX_PYLON_BATTERIES];

  bool isNormal() const
  {
    for(int ix=0; ix<MAX_PYLON_BATTERIES; ix++)
    {
      if(batts[ix].isPresent && 
         batts[ix].isNormal() == false)
      {
        return false;
      }
    }

    return true;
  }

  //in Wh
  long getPowerDC() const
  {
    return (long)(((double)currentDC/1000.0)*((double)avgVoltage/1000.0));
  }

  // power in Wh in charge
  float powerIN() const
  {
    if (currentDC > 0) {
       return (float)(((double)currentDC/1000.0)*((double)avgVoltage/1000.0));
    } else {
       return (float)(0);
    }
  }
  
  // power in Wh in discharge
  float powerOUT() const
  {
    if (currentDC < 0) {
       return (float)(((double)currentDC/1000.0)*((double)avgVoltage/1000.0)*-1);
    } else {
       return (float)(0);
    }
  }

  //Wh estimated current on AC side (taking into account Sofar ME3000SP losses)
  long getEstPowerAc() const
  {
    double powerDC = (double)getPowerDC();
    if(powerDC == 0)
    {
      return 0;
    }
    else if(powerDC < 0)
    {
      //we are discharging, on AC side we will see less power due to losses
      if(powerDC < -1000)
      {
        return (long)(powerDC*0.94);
      }
      else if(powerDC < -600)
      {
        return (long)(powerDC*0.90);
      }
      else
      {
        return (long)(powerDC*0.87);
      }
    }
    else
    {
      //we are charging, on AC side we will have more power due to losses
      if(powerDC > 1000)
      {
        return (long)(powerDC*1.06);
      }
      else if(powerDC > 600)
      {
        return (long)(powerDC*1.1);
      }
      else
      {
        return (long)(powerDC*1.13);
      }
    }
  }
};

batteryStack g_stack;


long extractInt(const char* pStr, int pos)
{
  return atol(pStr+pos);
}

void extractStr(const char* pStr, int pos, char* strOut, int strOutSize)
{
  strOut[strOutSize-1] = '\0';
  strncpy(strOut, pStr+pos, strOutSize-1);
  strOutSize--;
  
  
  //trim right
  while(strOutSize > 0)
  {
    if(isspace(strOut[strOutSize-1]))
    {
      strOut[strOutSize-1] = '\0';
    }
    else
    {
      break;
    }

    strOutSize--;
  }
}

/* Output has mixed \r and \r\n
pwr

@

Power Volt   Curr   Tempr  Tlow   Thigh  Vlow   Vhigh  Base.St  Volt.St  Curr.St  Temp.St  Coulomb  Time                 B.V.St   B.T.St
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
void loop() {
#ifdef ENABLE_MQTT
  mqttLoop();
#endif
  
  ArduinoOTA.handle();
  server.handleClient();

  //if there are bytes availbe on serial here - it's unexpected
  //when we send a command to battery, we read whole response
  //if we get anything here anyways - we will log it
  int bytesAv = Serial.available();
  if(bytesAv > 0)
  {
    if(bytesAv > 63)
    {
      bytesAv = 63;
    }
    
    char buff[64+4] = "RCV:";
    if(Serial.readBytes(buff+4, bytesAv) > 0)
    {
      //digitalWrite(LED, LOW);
      digitalWrite(LED, HIGH);
      delay(5);
      //digitalWrite(LED, HIGH);//high is off
      digitalWrite(LED, LOW);

      Log(buff);
    }
  }
}

#ifdef ENABLE_MQTT
#define ABS_DIFF(a, b) (a > b ? a-b : b-a)
void mqtt_publish_f(const char* topic, float newValue, float oldValue, float minDiff, bool force)
{
  char szTmp[16] = "";
  snprintf(szTmp, 15, "%.2f", newValue);
  if(force || ABS_DIFF(newValue, oldValue) > minDiff)
  {
    mqttClient.publish(topic, szTmp, false);
  }
}

void mqtt_publish_i(const char* topic, int newValue, int oldValue, int minDiff, bool force)
{
  char szTmp[16] = "";
  snprintf(szTmp, 15, "%d", newValue);
  if(force || ABS_DIFF(newValue, oldValue) > minDiff)
  {
    mqttClient.publish(topic, szTmp, false);
  }
}

void mqtt_publish_s(const char* topic, const char* newValue, const char* oldValue, bool force)
{
  if(force || strcmp(newValue, oldValue) != 0)
  {
    mqttClient.publish(topic, newValue, false);
  }
}

void pushBatteryDataToMqtt(const batteryStack& lastSentData, bool forceUpdate /* if true - we will send all data regardless if it's the same */)
{
  mqtt_publish_f(MQTT_TOPIC_ROOT "soc",          g_stack.soc,                lastSentData.soc,                0, forceUpdate);
  mqtt_publish_f(MQTT_TOPIC_ROOT "temp",         (float)g_stack.temp/1000.0, (float)lastSentData.temp/1000.0, 0.1, forceUpdate);
  mqtt_publish_i(MQTT_TOPIC_ROOT "currentDC",    g_stack.currentDC,          lastSentData.currentDC,          1, forceUpdate);
  mqtt_publish_i(MQTT_TOPIC_ROOT "estPowerAC",   g_stack.getEstPowerAc(),    lastSentData.getEstPowerAc(),   10, forceUpdate);
  mqtt_publish_i(MQTT_TOPIC_ROOT "battery_count",g_stack.batteryCount,       lastSentData.batteryCount,       0, forceUpdate);
  mqtt_publish_s(MQTT_TOPIC_ROOT "base_state",   g_stack.baseState,          lastSentData.baseState            , forceUpdate);
  mqtt_publish_i(MQTT_TOPIC_ROOT "is_normal",    g_stack.isNormal() ? 1:0,   lastSentData.isNormal() ? 1:0,   0, forceUpdate);
  mqtt_publish_i(MQTT_TOPIC_ROOT "getPowerDC",   g_stack.getPowerDC(),       lastSentData.getPowerDC(),       1, forceUpdate);
  mqtt_publish_i(MQTT_TOPIC_ROOT "powerIN",      g_stack.powerIN(),          lastSentData.powerIN(),          1, forceUpdate);
  mqtt_publish_i(MQTT_TOPIC_ROOT "powerOUT",     g_stack.powerOUT(),         lastSentData.powerOUT(),         1, forceUpdate);

  // publishing details
  for (int ix = 0; ix < g_stack.batteryCount; ix++) {
    char ixBuff[50];
    String ixBattStr = MQTT_TOPIC_ROOT + String(ix) + "/voltage";
    ixBattStr.toCharArray(ixBuff, 50);
    mqtt_publish_f(ixBuff, g_stack.batts[ix].voltage / 1000.0, lastSentData.batts[ix].voltage / 1000.0, 0, forceUpdate);
    ixBattStr = MQTT_TOPIC_ROOT + String(ix) + "/current";
    ixBattStr.toCharArray(ixBuff, 50);
    mqtt_publish_f(ixBuff, g_stack.batts[ix].current / 1000.0, lastSentData.batts[ix].current / 1000.0, 0, forceUpdate);
    ixBattStr = MQTT_TOPIC_ROOT + String(ix) + "/soc";
    ixBattStr.toCharArray(ixBuff, 50);
    mqtt_publish_i(ixBuff, g_stack.batts[ix].soc, lastSentData.batts[ix].soc, 0, forceUpdate);
    ixBattStr = MQTT_TOPIC_ROOT + String(ix) + "/charging";
    ixBattStr.toCharArray(ixBuff, 50);
    mqtt_publish_i(ixBuff, g_stack.batts[ix].isCharging()?1:0, lastSentData.batts[ix].isCharging()?1:0, 0, forceUpdate);
    ixBattStr = MQTT_TOPIC_ROOT + String(ix) + "/discharging";
    ixBattStr.toCharArray(ixBuff, 50);
    mqtt_publish_i(ixBuff, g_stack.batts[ix].isDischarging()?1:0, lastSentData.batts[ix].isDischarging()?1:0, 0, forceUpdate);
    ixBattStr = MQTT_TOPIC_ROOT + String(ix) + "/idle";
    ixBattStr.toCharArray(ixBuff, 50);
    mqtt_publish_i(ixBuff, g_stack.batts[ix].isIdle()?1:0, lastSentData.batts[ix].isIdle()?1:0, 0, forceUpdate);
    ixBattStr = MQTT_TOPIC_ROOT + String(ix) + "/state";
    ixBattStr.toCharArray(ixBuff, 50);
    mqtt_publish_s(ixBuff, g_stack.batts[ix].isIdle()?"Idle":g_stack.batts[ix].isCharging()?"Charging":g_stack.batts[ix].isDischarging()?"Discharging":"", lastSentData.batts[ix].isIdle()?"Idle":lastSentData.batts[ix].isCharging()?"Charging":lastSentData.batts[ix].isDischarging()?"Discharging":"", forceUpdate);
    ixBattStr = MQTT_TOPIC_ROOT + String(ix) + "/temp";
    ixBattStr.toCharArray(ixBuff, 50);
    mqtt_publish_f(ixBuff, (float)g_stack.batts[ix].tempr/1000.0, (float)lastSentData.batts[ix].tempr/1000.0, 0.1, forceUpdate);
  }
} 

void mqttLoop()
{
  //if we have problems with connecting to mqtt server, we will attempt to re-estabish connection each 1minute (not more than that)
  static unsigned long g_lastConnectionAttempt = 0;

  //first: let's make sure we are connected to mqtt
  const char* topicLastWill = MQTT_TOPIC_ROOT "availability";
  if (!mqttClient.connected() && (g_lastConnectionAttempt == 0 || os_getCurrentTimeSec() - g_lastConnectionAttempt > 60)) {
    if(mqttClient.connect(HOSTNAME, MQTT_USER, MQTT_PASSWORD, topicLastWill, 1, true, "offline"))
    {
      Log("Connected to MQTT server: " MQTT_SERVER);
      mqttClient.publish(topicLastWill, "online", true);
    }
    else
    {
      Log("Failed to connect to MQTT server.");
    }

    g_lastConnectionAttempt = os_getCurrentTimeSec();
  }

  //next: read data from battery and send via MQTT (but only once per MQTT_PUSH_FREQ_SEC seconds)
  static unsigned long g_lastDataSent = 0;
  if(mqttClient.connected() && 
     os_getCurrentTimeSec() - g_lastDataSent > MQTT_PUSH_FREQ_SEC &&
     sendCommandAndReadSerialResponse("pwr") == true)
  {
    static batteryStack lastSentData; //this is the last state we sent to MQTT, used to prevent sending the same data over and over again
    static unsigned int callCnt = 0;
    
    parsePwrResponse(g_szRecvBuff);

    bool forceUpdate = (callCnt % 20 == 0); //push all the data every 20th call
    pushBatteryDataToMqtt(lastSentData, forceUpdate);
    
    callCnt++;
    g_lastDataSent = os_getCurrentTimeSec();
    memcpy(&lastSentData, &g_stack, sizeof(batteryStack));
  }
  
  mqttClient.loop();
}

#endif //ENABLE_MQTT

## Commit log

2025-03-06 Add files via upload
    PCB-layout and PCB-schematics
    [pylontec_LAN_interface.brd, pylontec_LAN_interface.sch]
2025-03-06 Add files via upload
    these are the .stl files for a case-box for the pcb with different setup possibilities
    [Stoppel_antenne.stl, Stoppel_console.stl, deckel_fusioned.stl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]
